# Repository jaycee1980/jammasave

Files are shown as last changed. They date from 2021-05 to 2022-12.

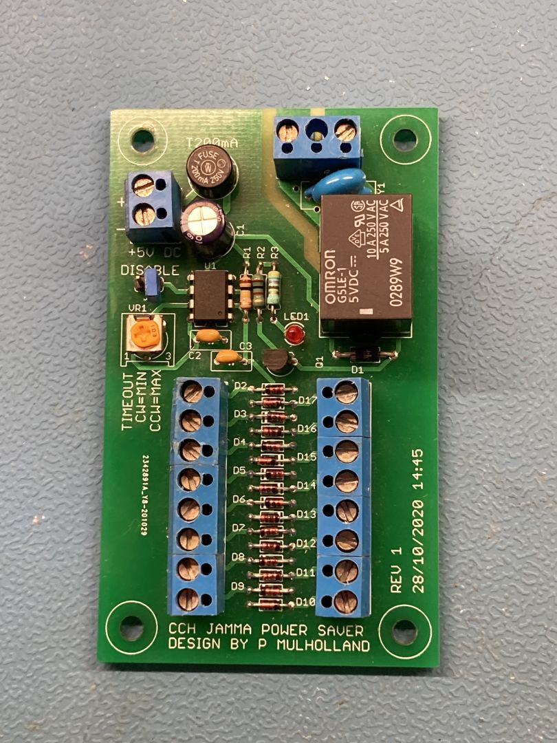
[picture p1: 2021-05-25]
media/Assembled Board.jpg

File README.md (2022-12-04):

# jammasave
A CRT power saver for JAMMA arcade cabinets.

Picture of the board

At the [Centre for Computing History](http://www.computinghistory.org.uk) we have a few arcade cabinets for visitors to play on. These traditionally use CRT monitors -  CRT's are a problem, because they wear out with use, and draw quite a bit of power. The machines stand idle often, so the CRT displays are needlessly on, being worn down and costing extra money to run. As CRT's are no longer being made, it can be problematic to replace them when they fail.

PC's solved this issue by having screensavers that power off the monitor when the machine is idle. However, arcade machines typically run an "attract" mode to entice people to play on them, thus there is no such setting.

So what do we do ? Solve it with extra hardware of course :)

## How it works

The board is designed to be wired to 5V power (easily obtainable in an arcade cabinet), and has a relay which is normally switched on, but switches off when a timeout period expires. There are  16 "wire-OR'd" inputs which are connected to the JAMMA connectors input pins (See https://wiki.arcadeotaku.com/w/JAMMA for more info). When any of these 16 inputs are pulled low (i.e. the user presses a button or pushes a direction), the timer is reset. The CRT's power feed can be wired through this relay so that it is switched off when the timer expires.

A preset potentiometer allows the timeout period to be adjusted from 30 minutes to 1½ hours. This can be further adjusted in the software if required.
A jumper can also put the board into "disable" mode, where the relay is switched on and nothing else happens. This is useful for servicing.

# Details

The design is based around an [Atmel ATtiny13 microcontroller](https://www.microchip.com/wwwproducts/en/ATtiny13). An internal 4.8MHz oscillator means there is no need for an external timing crystal.

The internal ADC allows a simple preset potentiometer, wired as a potential divider, to be used in order to set the timeout delay. The ADC simply reads a value between 0-1023 which is then used to set the initial value of the timeout counter.

One GPIO port is configured as an output, and used to control a a "sugar cube" type relay, via a BC337 transistor. The relay is a 5V type so that only a 5V supply is required. This relay then controls the CRT by switching it's power feed.

JAMMA inputs are active low, so this means that multiple inputs can be catered for simply by using diodes. A GPIO pin is configured as an input, which is normally pulled up th +5V via a 100K resistor. A path to ground through any one of the diodes pulls the input low, which is detected by using pin change interrupts.

The timeout period is implemented using Timer/Counter 0. This is configured to generate ~500 ticks/second. This is used to decrement a tiemout counter which is initially set according to the timeout period required. Once this counter reaches zero, the relay is switched off. If the pin change interrupt fires due to an input, the timeout counter is reset.

# Whats in this repo

This repo contains the EAGLE design files, Gerber files suitable for manufacturing, the C source code and Atmel Studio project files used to compile the code.

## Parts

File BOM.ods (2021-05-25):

Part Designator | Qty | Manufacturer PN | Manufacturer | Description | Digikey PN | Notes
U1 | 1 | ATTINY13V-10PU | Microchip | IC MCU 8BIT 1KB FLASH 8DIP | ATTINY13V-10PU-ND | ATtiny13A should also work
R1 | 1 |  | Generic | 100K Resistor 1/4W | CF14JT100KCT-ND
R2 | 1 |  | Generic | 1K Resistor 1/4W | CF14JT1K00CT-ND
R3 | 1 |  | Generic | 470R Resistor 1/4W | CF14JT470RCT-ND | May be omitted with LED1 if status LED not required
D1 | 1 | 1N4004 | Generic | DIODE GEN PURP 400V 1A DO41 | 1N4004RLGOSCT-ND
D2-D17 | 16 | 1N4148 | Generic | DIODE GEN PURP 100V 200MA DO35 | 1N4148FSCT-ND
C1 | 1 |  | Generic | Electrolytic Capacitor, 220uF 16V , 3.5mm pitch, 8mm dia | 493-11579-1-ND
C2-C3 | 2 |  | Generic | Ceramic Capacitor, 100NF 100V, 5mm pitch | 399-4329-ND
Q1 | 1 | BC337-40 | Generic | TRANSISTOR NPN 45V 800MA TO92-3 | BC33740TACT-ND
CY1 | 1 |  | Generic | 4n7 Film Capacitor 275VAC X2 | 399-5989-ND | Relay contact suppression, don't omit!!
VR1 | 1 | 601030 | AVX | 10K Trimmer, Single turn, linear | 478-601030-ND
(alt) | 1 | 3306F-1-103 | Bourns | TRIMMER 10K OHM 0.2W PC PIN TOP | 3306F-103-ND
K1 | 1 | G5LE-1 DC5 | Omron | Relay SPDT (1 Form C) 5VDC Coil 10A | Z1014-ND | "Sugar Cube" format relay
(alt) | 1 | ORWH-SH-105D1F,000 | TE Connectivity | RELAY GEN PURPOSE SPDT 10A 5V | PB2032-ND
F1 | 1 | MRT 200-BULK | Bel Fuse Inc. | FUSE BOARD MNT T200MA 250VAC RAD | 507-1104-ND
(alt) | 1 | RST 200 AMMO | Bel Fuse Inc. | FUSE BOARD MNT T200MA 250VAC RAD | RST200AMMO-ND
(alt) | 1 | 37202000411 | Littelfuse | FUSE BOARD MNT T200MA 250VAC RAD | WK4234BK-ND
JP1 | 1 |  | Generic | 0.1" (2.54mm) PIN HEADER, 2WAY | S1012EC-02-ND | May be omitted if DISABLE feature not required
LED1 | 1 |  | Generic | 3MM RED LED | 160-1035-ND | May be omitted with R3 if status LED not required
CN1, CN3-CN10 | 9 | 5442206 | Phoenix Contact | TERM BLK 2P SIDE ENT 5.08MM PCB | 277-12547-ND
(alt) | 1 | OSTTA024163 | On Shore Technology Inc. | TERM BLK 2P SIDE ENT 5.08MM PCB | ED2580-ND
(alt) | 1 | 691213510002 | Würth Elektronik | 5.08 MM TERMINAL BLOCK, HORIZONT | 732-691213510002-ND
CN2 | 1 | 1717729 | Phoenix Contact | TERM BLK 2P SIDE ENT 7.62MM PCB | 277-5998-ND | PCB will take either 7.62mm or 10.16mm pitch
(alt) | 1 | OSTTC023162 | On Shore Technology Inc. | TERM BLK 2P SIDE ENT 10.16MM PCB | ED2653-ND
(alt) | 1 | 691216410002 | Würth Elektronik | TERM BLK 2P SIDE ENT 7.62MM PCB | 732-10975-ND
(alt) | 1 | 691216610002 | Würth Elektronik | TERM BLK 2P SIDE ENT 10.16MM PCB | 732-11177-ND

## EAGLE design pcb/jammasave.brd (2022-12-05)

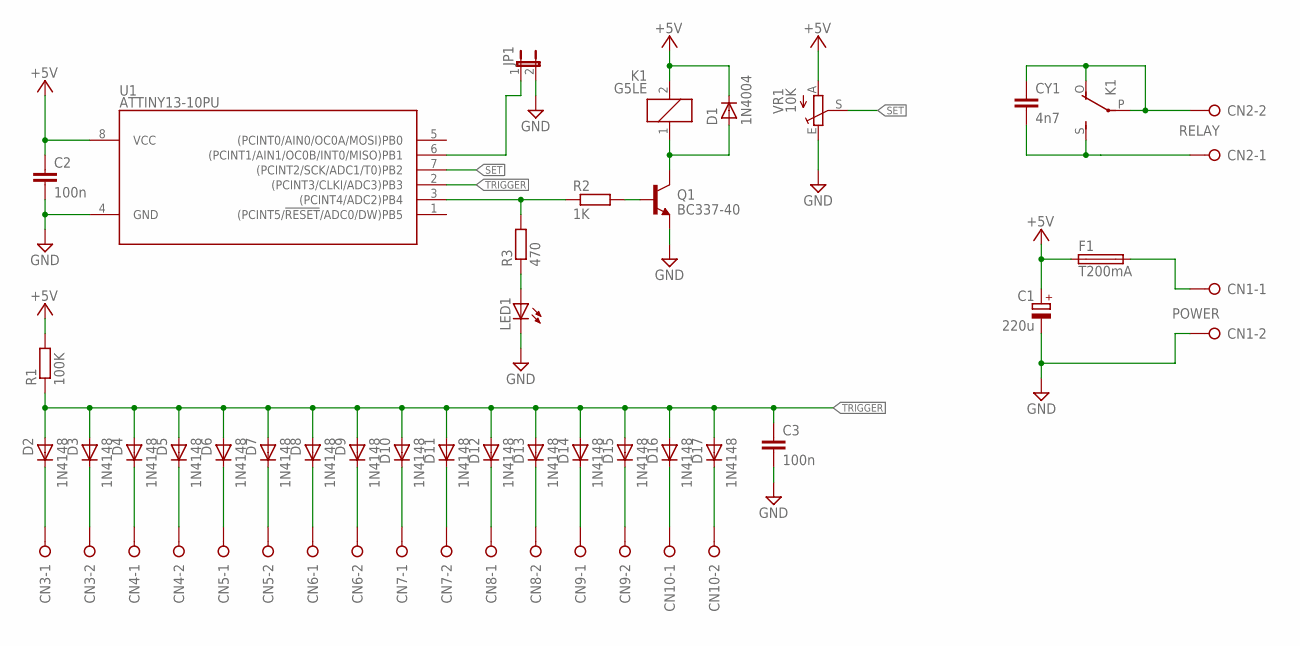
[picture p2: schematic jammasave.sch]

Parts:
C1: 220u; E3,5-8
C2, C3: 100n; C050-035X075
CN1: POWER; W237-132
CN2: RELAY; W237-2N
CN3, CN4, CN5, CN6, CN7, CN8, CN9, CN10: W237-02P; W237-132
CY1: 4n7; YC10B5
D1: 1N4004; DO41-10
D2, D3, D4, D5, D6, D7, D8, D9, D10, D11, D12, D13, D14, D15, D16, D17: 1N4148; DO35-7
F1: T200mA; TE5
JP1: JP1E; JP1
K1: G5LE
LED1: LED3MM
Q1: BC337-40; TO92-254
R1: 100K; 0207/10
R2: 1K; 0207/10
R3: 470; 0207/10
U1: ATTINY13-10PU; DIL08
VR1: 10K; CA6V

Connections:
+5V: C1.+, C2.1, D1.K (C), F1.1, K1.2, R1.2, U1.8 (VCC), VR1.A
GND: C1.-, C2.2, C3.2, CN1.2, JP1.2, LED1.K (C), Q1.3 (E), U1.4 (GND), VR1.E
unnamed: Q1.2 (B), R2.2
unnamed: D1.A, K1.1, Q1.1 (C)
unnamed: R2.1, R3.2, U1.3 ((PCINT4/ADC2)PB4)
unnamed: CN1.1, F1.2
unnamed: LED1.A, R3.1
unnamed: JP1.1, U1.6 ((PCINT1/AIN1/OC0B/INT0/MISO)PB1)
unnamed: CN2.2, CY1.1, K1.O, K1.P
unnamed: CN2.1, CY1.2, K1.S
unnamed: CN3.1, D2.K (C)
unnamed: CN3.2, D3.K (C)
unnamed: CN4.1, D4.K (C)
unnamed: CN4.2, D5.K (C)
unnamed: CN5.1, D6.K (C)
unnamed: CN5.2, D7.K (C)
unnamed: CN6.1, D8.K (C)
unnamed: CN6.2, D9.K (C)
unnamed: CN7.1, D10.K (C)
unnamed: CN7.2, D11.K (C)
unnamed: CN8.1, D12.K (C)
unnamed: CN8.2, D13.K (C)
unnamed: CN9.1, D14.K (C)
unnamed: CN9.2, D15.K (C)
unnamed: CN10.1, D16.K (C)
unnamed: CN10.2, D17.K (C)
SET: U1.7 ((PCINT2/SCK/ADC1/T0)PB2), VR1.S
TRIGGER: C3.1, D2.A, D3.A, D4.A, D5.A, D6.A, D7.A, D8.A, D9.A, D10.A, D11.A, D12.A, D13.A, D14.A, D15.A, D16.A, D17.A, R1.1, U1.2 ((PCINT3/CLKI/ADC3)PB3)

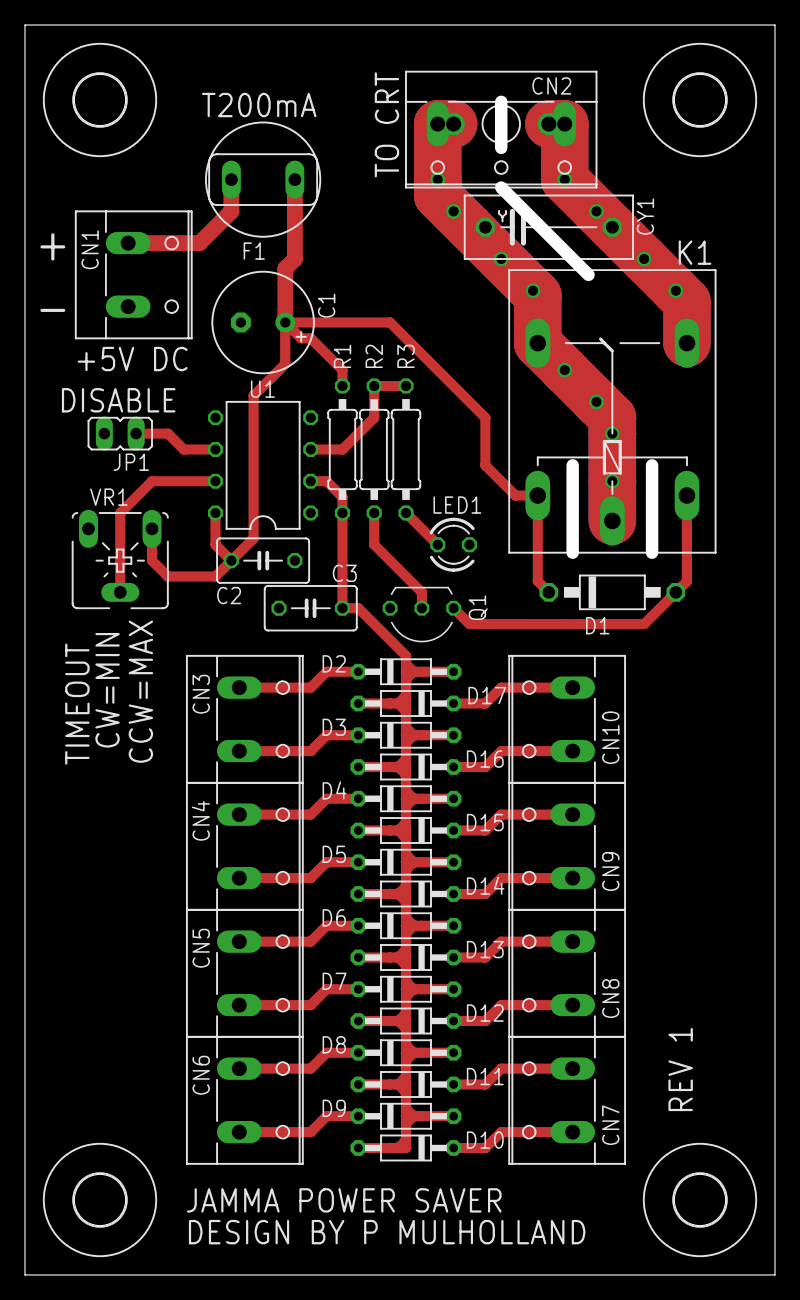
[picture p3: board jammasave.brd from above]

Board: 2 copper layers, 60.0 x 100.0 mm, 45 parts (0 on the bottom side), 28 nets.

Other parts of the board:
U$1, U$2, U$3, U$4: 4,1

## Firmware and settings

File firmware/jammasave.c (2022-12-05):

/*******************************************************************************************************************//**
	JAMMA cabinet power saver
	\author Peter Mulholland
***********************************************************************************************************************/

// avr-gcc -mmcu=attiny13a -Os -std=c99 jammasave.c -o jammasave.elf
// avrdude -p t13 -b 19200 -c usbasp-clone -P com4 -v -U flash:w:jammasave.elf -U hfuse:w:0xF8:m -U lfuse:w:0x71:m

#define F_CPU 4800000UL

#include <stdint.h>
#include <avr/io.h>
#include <avr/sleep.h>
#include <avr/wdt.h>
#include <avr/interrupt.h>
#include <avr/cpufunc.h>
#include <avr/pgmspace.h>

//----------------------------------------------------------------------------------------------------------------------
// Fuse settings

FUSES = {
	.low = (FUSE_SPIEN & FUSE_SUT1 & FUSE_SUT0 & FUSE_CKSEL1),		// SPI programming, 4.8MHz internal clock, minimal reset delay
	.high = (FUSE_BODLEVEL1 & FUSE_BODLEVEL0 & FUSE_RSTDISBL)		// brownout at 4.3v, reset pin disabled
};

//----------------------------------------------------------------------------------------------------------------------
// Constants and Defines

// The timer ticks at 75KHz. A count of 150 means our ISR triggers every 5KHz
#define TIMER_COUNT		(256-150)

// So, 500 ticks = 1 second.
// In reality it's a little inaccurate because the 4.8MHz internal clock isn't that accurate.
#define TIMER_TICKS_PER_SEC		500

//----------------------------------------------------------------------------------------------------------------------
// PROGMEM data

static const char c_credits[] __attribute__((used)) PROGMEM = "JAMMA Power Saver built " __DATE__ " " __TIME__;

//----------------------------------------------------------------------------------------------------------------------
// EEMEM data

//----------------------------------------------------------------------------------------------------------------------
// Global variables

uint32_t g_timer = 0;
uint32_t g_timeout = 0;

//----------------------------------------------------------------------------------------------------------------------
// Local Functions

uint16_t read_adc()
{
	ADCSRA |= (1 << ADSC);									// Start conversion
	while (!(ADCSRA & (1 << ADIF)));						// Wait for it to complete
	ADCSRA |= (1 << ADIF);									// Clear completion bit

	return ADCW;
}

void read_timeout_setting()
{
	// Set up ADC with ADC1 (PB2) as the input
	DIDR0 = (1 << ADC1D);									// Disable digital IO on PB2
	ADMUX = (1 << MUX1);									// Use Vcc as reference, right adjusted result, input from ADC1 (PB2)
	ADCSRB = 0;
	ADCSRA = (1 << ADEN) | (1 << ADPS2) | (1 << ADPS0);		// Enable ADC, no interrupt, CLK/32 (150KHz)
	_NOP();
	_NOP();

	// Do some dummy readings to allow ADC to settle
	for (uint8_t i = 0; i < 8; i++)
		read_adc();

	// Read ADC for timeout scale value (0 - 511)
	uint16_t tcnt = read_adc() >> 1;

	// Set timer to the timeout count - between 1/2 hour and 1 1/2 hour.
	//	g_timeout =  1800 + ((((3600 * 32) / 512) * (uint32_t) tcnt) / 32);
	g_timeout  = ((225UL * (uint32_t) tcnt) / 32UL ) +	300UL; //+ 1800UL;
	g_timeout *= (uint32_t) TIMER_TICKS_PER_SEC;

	// We don't use the ADC any more, so turn it off
	ADCSRA = 0;
	PRR = (1 << PRADC);
}

//----------------------------------------------------------------------------------------------------------------------
// ISR's

ISR(TIM0_OVF_vect)
{
	// If we go over the timeout count, turn the relay off and stop the timer
	// We then wait for a pin change interrupt to wake things up again

	if (g_timer-- == 0)
	{
		// Turn relay off
		PORTB &= ~(1 << PORTB4);

		// Stop the timer
		TCCR0B = 0;
	}
	else
	{
		// Go for another round
		TCNT0 = TIMER_COUNT;
	}

	TIFR0 &= ~(1 << TOV0);
}

ISR(PCINT0_vect)
{
	// If our pin change was low, the user pressed a control. Stop timer, and turn the relay on if it isn't.
	// if our pin change was high, reset and start the timer again.
	// This behaviour means that a stuck-on input will only result in the timeout never happening...
	if ((PINB & (1 << PINB3)) == 0)
	{
		// Turn the relay on if it isn't already
		PORTB |= (1 << PORTB4);

		// Stop the timer
		TCCR0B = 0;
	}
	else
	{
		// Reset and start the timer
		g_timer = g_timeout;

		TCNT0 = TIMER_COUNT;
		TCCR0B = (1 << CS01) | (1 << CS00);
	}
}

//----------------------------------------------------------------------------------------------------------------------
// Main

void main(void) __attribute__((noreturn));

void main(void)
{
	// Disable the watchdog timer
	wdt_disable();

	// Enable pullup on PB1, set output ports low
	PORTB = (1 << PORTB1);

	// Set PB4 as output (relay control), the rest to inputs
	DDRB = (1 << DDB4);

	// Wait for port state to synchronise before reading it
	_NOP();
	_NOP();

	// Check if the "disable" jumper connected to PB1 is present (PB1 will be pulled low)
	// If it is, we don't do anything else - just turn on the relay and go to sleep permanently

	if (!(PINB & (1 << PINB1)))
	{
		// Turn relay on
		PORTB |= (1 << PORTB4);

		// We never wake up again...
		set_sleep_mode(SLEEP_MODE_PWR_DOWN);
	}
	else
	{
		// Set up pin change interrupt for PB3
		PCMSK = (1 << PCINT3);
		GIMSK = (1 << PCIE);

		// Read the ADC for our timeout setting
		read_timeout_setting();
		//g_timeout = 1800;

		// Turn relay on
		PORTB |= (1 << PORTB4);

		// Set timeout counter
		g_timer = g_timeout;

		// Set up the overflow timer. 4.8MHz / 64 = ticks at 75KHz.
		TIMSK0 = (1 << TOIE0);					// TIMER0_OVF interrupt on
		TIFR0 = 0;								// Clear timer flags
		TCCR0A = 0;								// No compare match output, normal waveform mode

		TCNT0 = TIMER_COUNT;
		TCCR0B = (1 << CS01) | (1 << CS00);		// Set divider and start

		sei();									// Enable interrupts so that timer overflow and pin change wake us up

		// Set our sleep mode so timer and pin change interrupts work
		set_sleep_mode(SLEEP_MODE_IDLE);
	}

	// Interrupts do the rest, sit here and sleep
	for (;;)
	{
		sleep_enable();
		sleep_cpu();
	}
}

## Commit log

2021-05-25 Initial checkin
    [jammasave.GBL, jammasave.GBO, jammasave.GBP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]
2021-05-25 PDF of the schematic and a photo of the assembled board
2021-05-25 Make sure TOV0 bit is always cleared after a timer overflow interrupt
2021-05-25 Bill of materials
    [BOM.ods]
2021-05-25 Corrected BOM value for C1
    [BOM.ods]
2021-05-26 Correct potential underflow issue on timeout counter
    [jammasave.c]
2022-12-05 Remove CCH "branding"
    [jammasave.GBL, jammasave.GBO, jammasave.GBP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]
